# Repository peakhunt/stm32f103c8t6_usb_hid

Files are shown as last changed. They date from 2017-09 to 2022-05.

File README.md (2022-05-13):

# stm32f103c8t6_usb_hid

This is a USB joystick demo using STM32F103C8T6.
The whole project was developed using CubeMX.

## hardware
Basically I used very cheap chinese STM32F103 module. [The link is here][1]

As for arcade style joysticks and push buttons, there are a bunch of
cheap chinese stuffs out there.

As for connection, please refer to the kicad directory. It's gonna cost about $10 US dollars to get the 10 custom PCBs from cheap PCB manufactureres. Whether you use custom soldering or PCB based approach, just be sure to pay attention to the capacitor to prevent debouncing .  And just bear in mind that I am a S/W enginner. Designing a simple H/W like this is just a kind of my hobby.

[1]: https://www.aliexpress.com/item/Free-Shipping-STM32F103C8T6-ARM-STM32-Minimum-System-Development-Board-Module-For-arduino/32555258029.html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,searchweb201602_5_5460015_10152_10065_10151_10068_5470015_10307_10137_10060_10155_10154_10056_10055_10054_10059_100031_10099_10338_10339_5380015_10103_10102_440_10052_10053_10142_10107_10050_10051_10326_10084_10083_10080_10082_10081_10110_10175_10111_10112_10113_10114_143_10037_10312_10313_10314_10078_10079_10077_10073,searchweb201603_19,ppcSwitch_5&btsid=67a13b36-0190-4c70-9deb-1a2744050228&algo_expid=c62760bd-a140-4c3e-86ec-c725bdf3f0dc-14&algo_pvid=c62760bd-a140-4c3e-86ec-c725bdf3f0dc

## my build
Here is a demo joystick I built. I've been having some fun using it with retroarch. I love kungfu master.

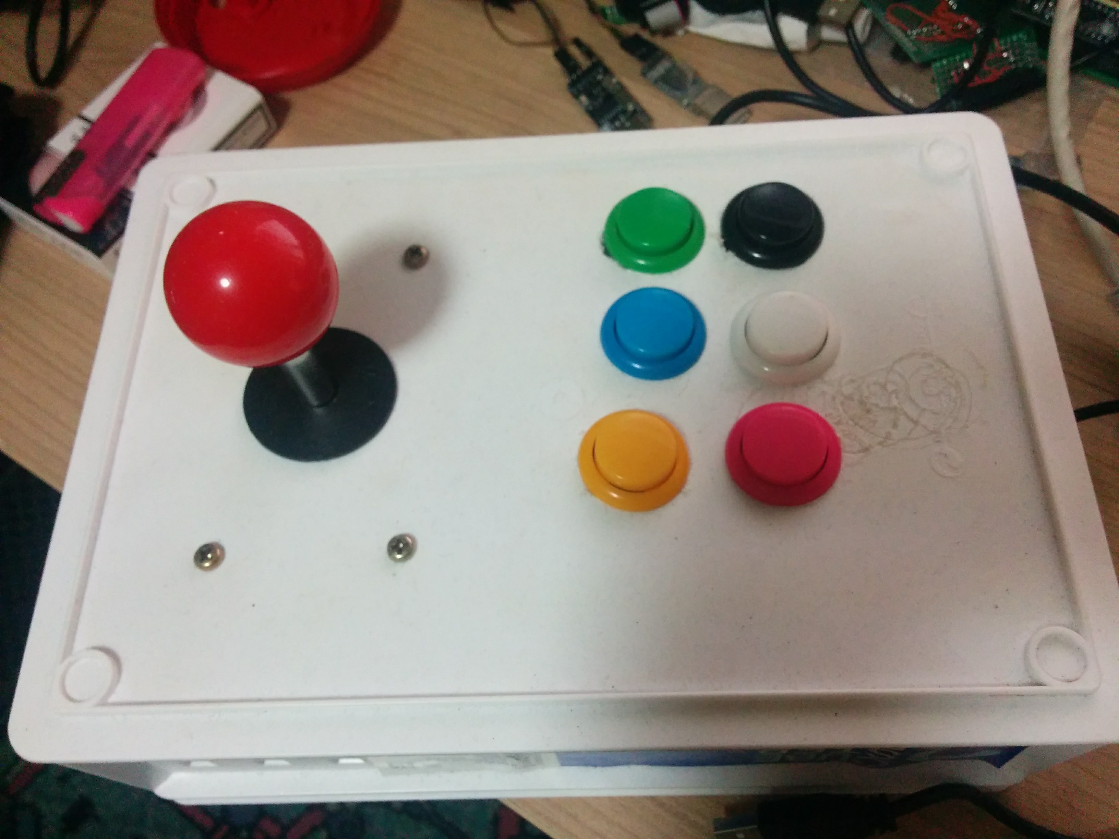
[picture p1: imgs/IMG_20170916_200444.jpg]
joystick build


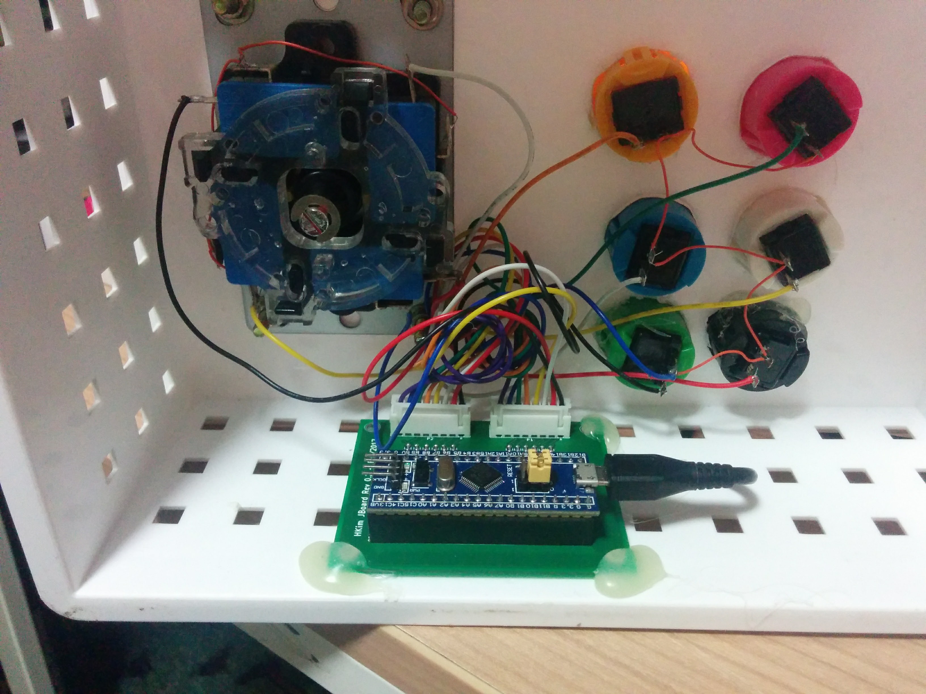
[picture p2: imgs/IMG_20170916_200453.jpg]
joystick build inside


The case is actually a small rectangular plastic container ( or basket or whatever). I bought it at less than 2 dollars at a local store and drilled it.

Here is the image of PCB I created for the build. It's really primitive simple board and anybody can do it. I just hated all the stupid fragile wiring I had to do before the PCB.

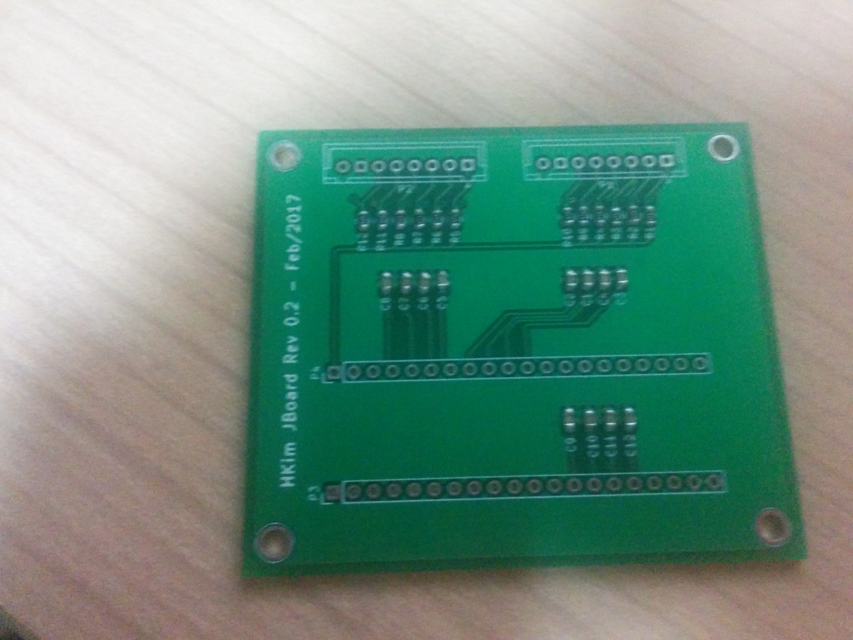
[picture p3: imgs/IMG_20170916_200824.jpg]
jostick board


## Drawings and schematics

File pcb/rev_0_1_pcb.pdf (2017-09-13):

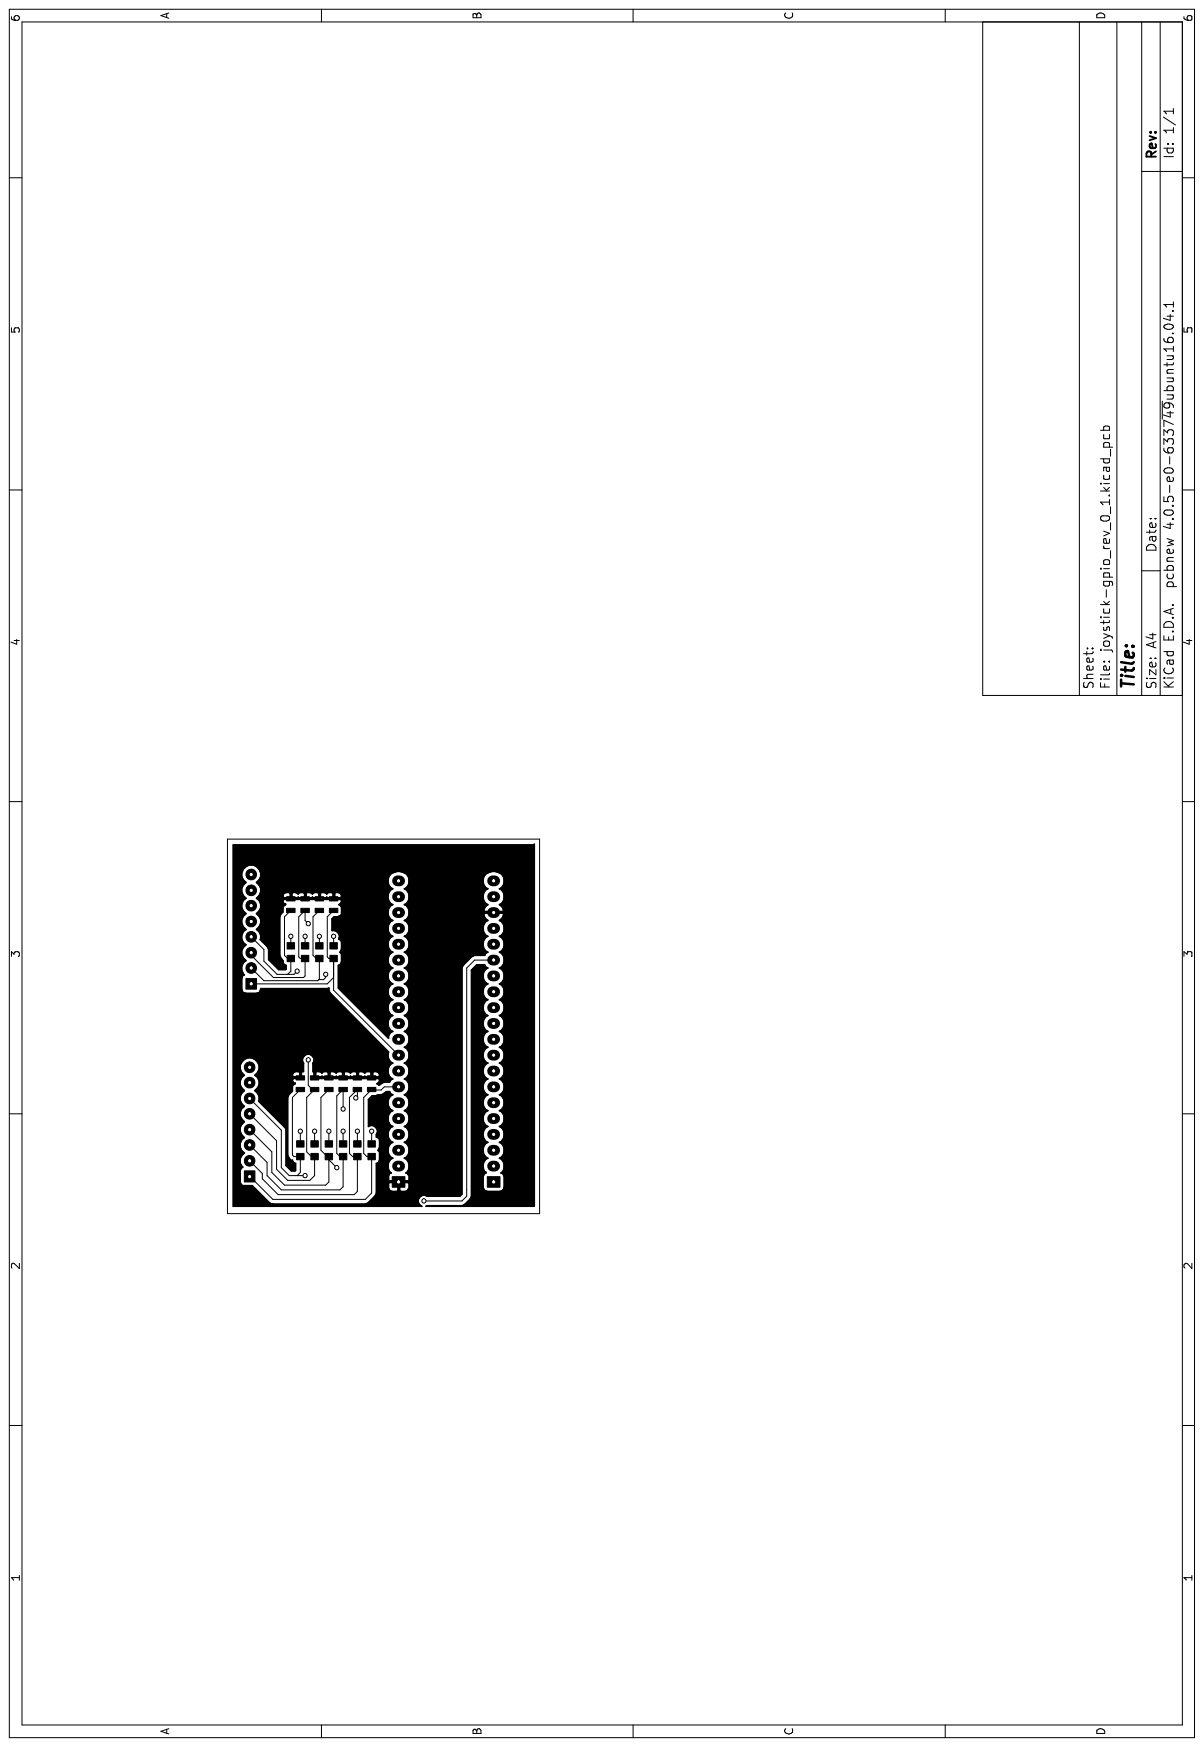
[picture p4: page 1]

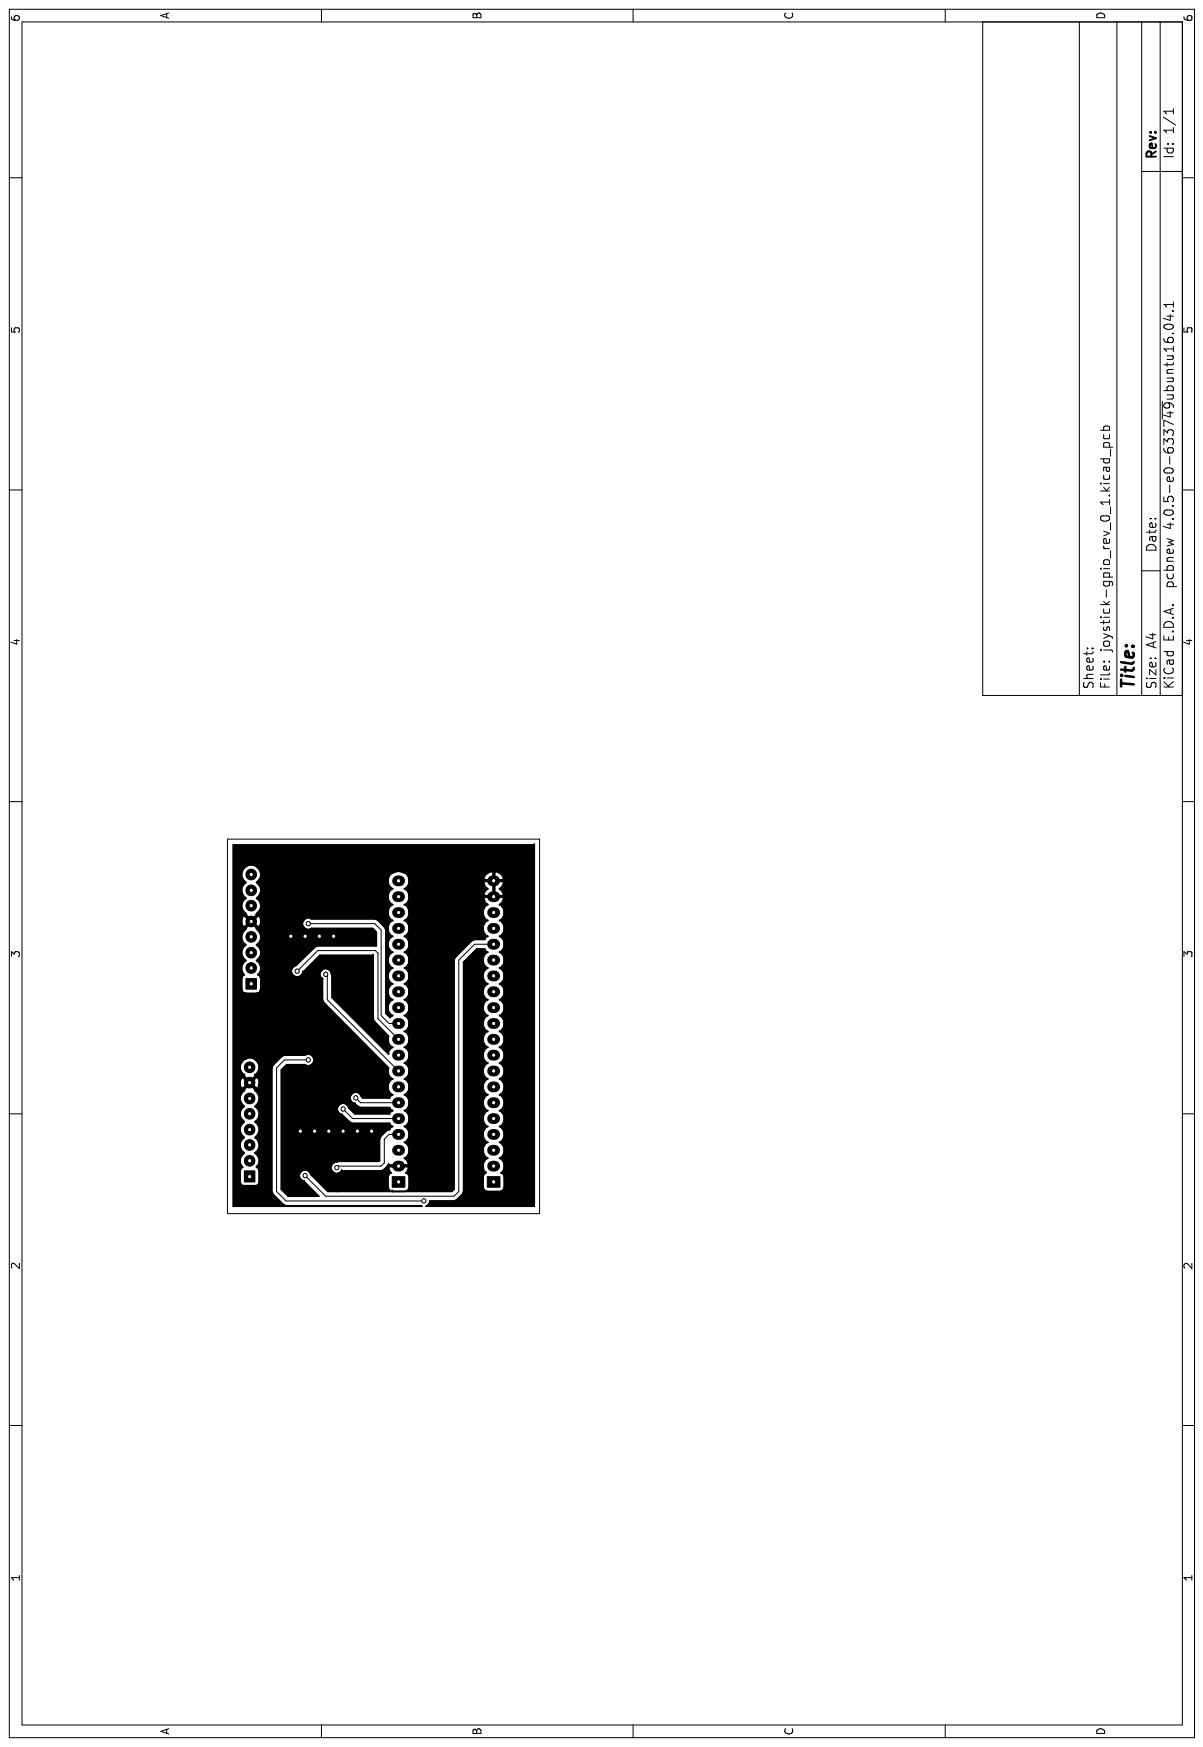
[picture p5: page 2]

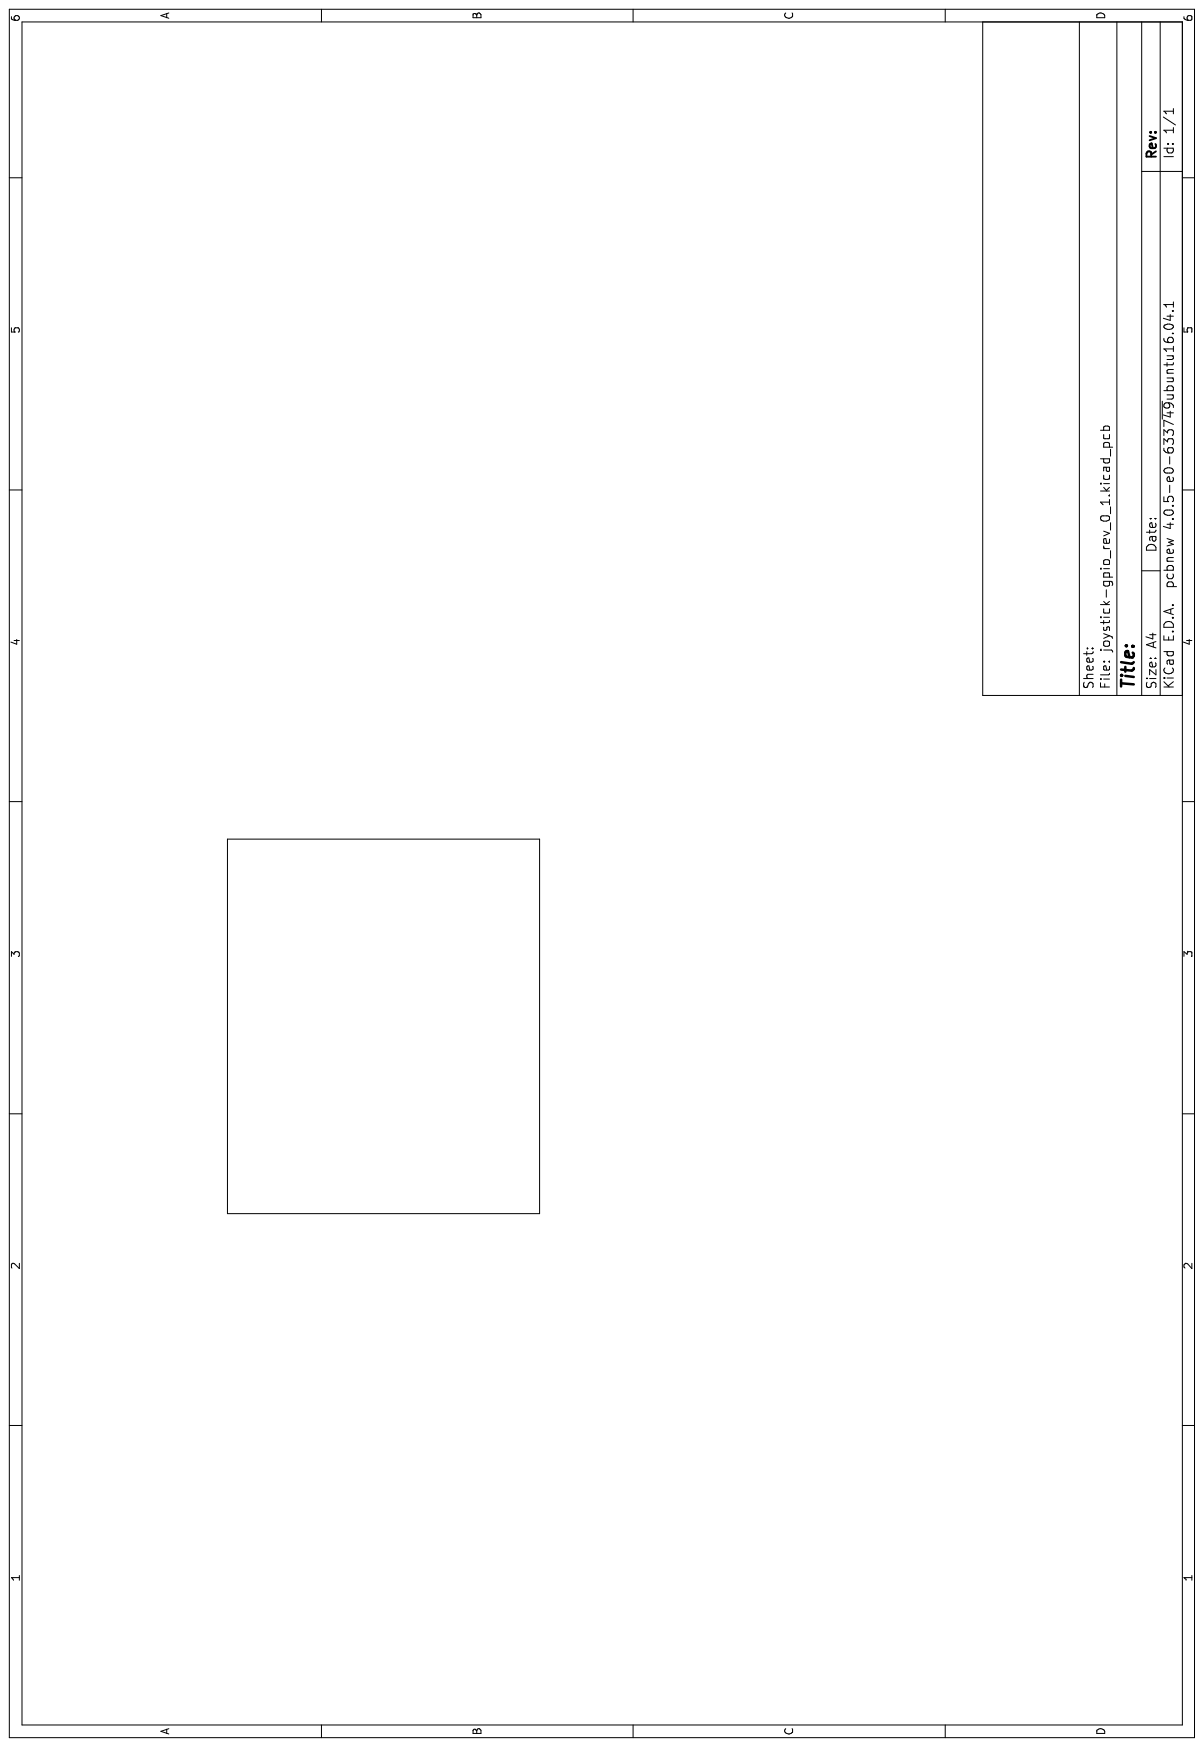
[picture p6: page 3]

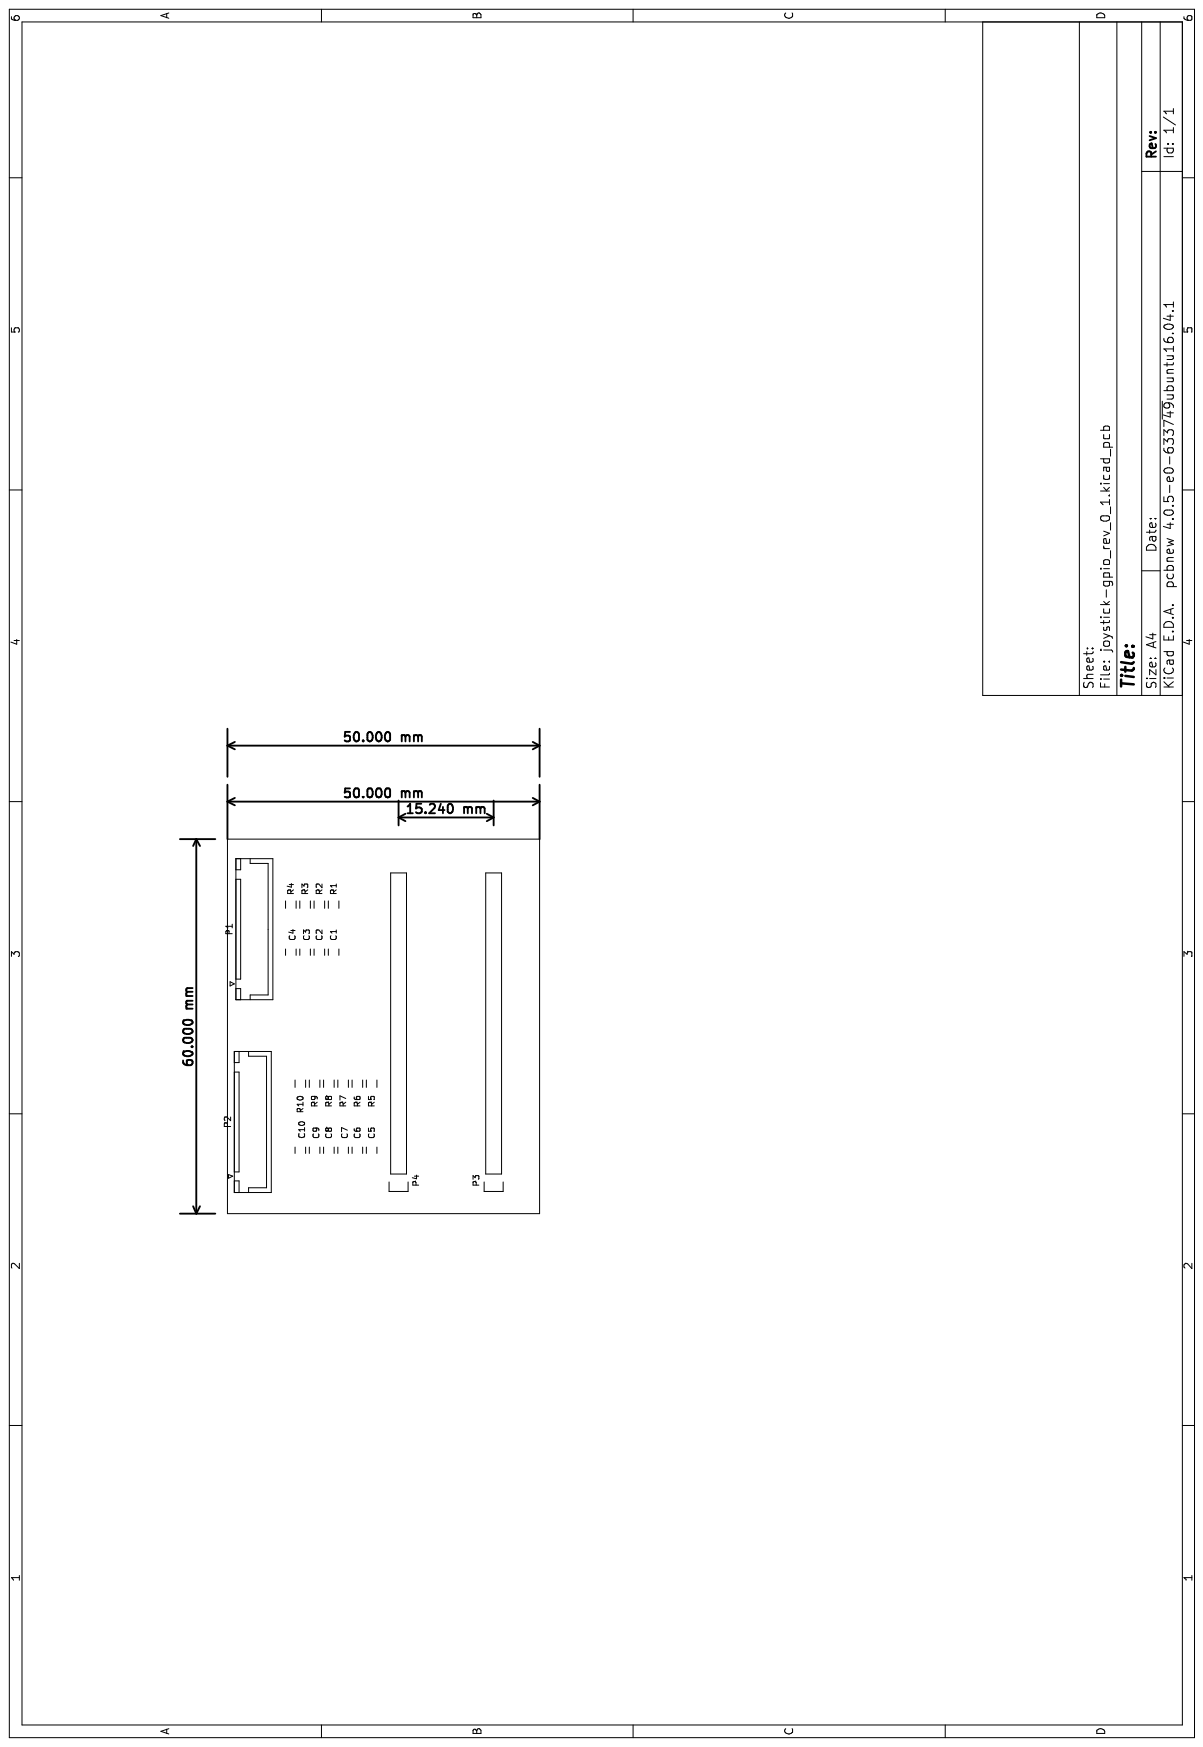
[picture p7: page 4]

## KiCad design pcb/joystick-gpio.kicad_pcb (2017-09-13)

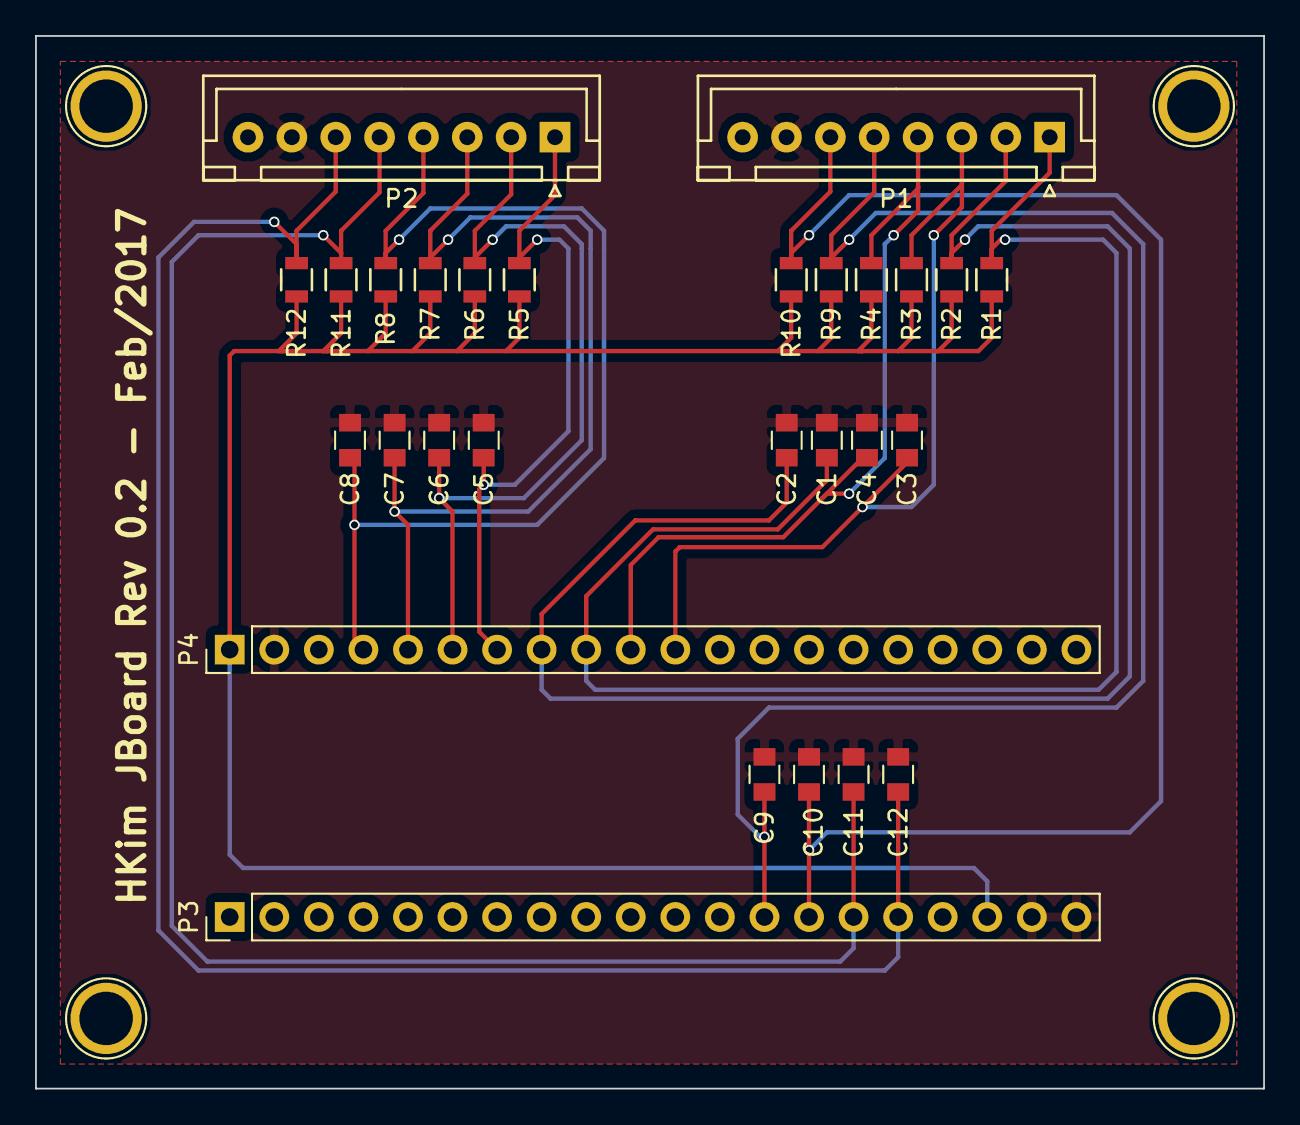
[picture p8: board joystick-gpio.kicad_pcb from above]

Board: 2 copper layers, 70.0 x 60.0 mm, 28 parts (0 on the bottom side), 14 nets.

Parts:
C1, C2, C3, C4, C5, C6, C7, C8, C9, C10, C11, C12: 100nF; C_0805
P1, P2: CONN_01X08; JST_XH_B08B-XH-A_08x2.50mm_Straight
P3, P4: CONN_01X20; Socket_Strip_Straight_1x20_Pitch2.54mm
R1, R2, R3, R4, R5, R6, R7, R8, R9, R10, R11, R12: 47K; R_0805

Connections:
/3.3V: P3.18, P4.1, R1.2, R2.2, R3.2, R4.2, R5.2, R6.2, R7.2, R8.2, R9.2, R10.2, R11.2, R12.2
/GROUND: C1.1, C2.1, C3.1, C4.1, C5.1, C6.1, C7.1, C8.1, C9.1, C10.1, C11.1, C12.1, P1.7, P2.7, P3.19, P3.20, P4.2
/JBT0: C5.2, P2.1, P4.7, R5.1
/JBT1: C6.2, P2.2, P4.6, R6.1
/JBT2: C7.2, P2.3, P4.5, R7.1
/JBT3: C8.2, P2.4, P4.4, R8.1
/JBT4: C9.2, P1.5, P3.13, R9.1
/JBT5: C10.2, P1.6, P3.14, R10.1
/JDOWN: C2.2, P1.2, P4.8, R2.1
/JLEFT: C3.2, P1.3, P4.11, R3.1
/JRIGHT: C4.2, P1.4, P4.10, R4.1
/JSELECT: C12.2, P2.6, P3.16, R12.1
/JSTART: C11.2, P2.5, P3.15, R11.1
/JUP: C1.2, P1.1, P4.9, R1.1

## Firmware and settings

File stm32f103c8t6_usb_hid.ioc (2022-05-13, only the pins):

Mcu.UserName=STM32F103C8Tx
PA0-WKUP.Signal=ADCx_IN0
PA1.Signal=ADCx_IN1
PA11.Signal=USB_DM
PA12.Signal=USB_DP
PA13.Signal=SYS_JTMS-SWDIO
PA14.Signal=SYS_JTCK-SWCLK
PA15.GPIO_Label=joystick_left
PA15.Signal=GPIO_Input
PA2.Signal=ADCx_IN2
PA3.Signal=ADCx_IN3
PA4.Signal=ADCx_IN4
PA5.Signal=ADCx_IN5
PA6.Signal=ADCx_IN6
PA7.Signal=ADCx_IN7
PB10.Signal=I2C2_SCL
PB11.Signal=I2C2_SDA
PB12.Signal=SPI2_NSS
PB13.Signal=SPI2_SCK
PB14.Signal=SPI2_MISO
PB15.Signal=SPI2_MOSI
PB3.GPIO_Label=joystick_right
PB3.Signal=GPIO_Input
PB4.GPIO_Label=joystick_up
PB4.Signal=GPIO_Input
PB5.GPIO_Label=joystick_down
PB5.Signal=GPIO_Input
PB6.GPIO_Label=joystick_button0
PB6.Signal=GPIO_Input
PB7.GPIO_Label=joystick_button1
PB7.Signal=GPIO_Input
PB8.GPIO_Label=joystick_button2
PB8.Signal=GPIO_Input
PB9.GPIO_Label=joystick_button3
PB9.Signal=GPIO_Input
PC13-TAMPER-RTC.GPIO_Label=led
PC13-TAMPER-RTC.Signal=GPIO_Output
PD0-OSC_IN.Signal=RCC_OSC_IN
PD1-OSC_OUT.Signal=RCC_OSC_OUT

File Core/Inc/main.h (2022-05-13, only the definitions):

#define led_Pin GPIO_PIN_13
#define led_GPIO_Port GPIOC
#define joystick_left_Pin GPIO_PIN_15
#define joystick_left_GPIO_Port GPIOA
#define joystick_right_Pin GPIO_PIN_3
#define joystick_right_GPIO_Port GPIOB
#define joystick_up_Pin GPIO_PIN_4
#define joystick_up_GPIO_Port GPIOB
#define joystick_down_Pin GPIO_PIN_5
#define joystick_down_GPIO_Port GPIOB
#define joystick_button0_Pin GPIO_PIN_6
#define joystick_button0_GPIO_Port GPIOB
#define joystick_button1_Pin GPIO_PIN_7
#define joystick_button1_GPIO_Port GPIOB
#define joystick_button2_Pin GPIO_PIN_8
#define joystick_button2_GPIO_Port GPIOB
#define joystick_button3_Pin GPIO_PIN_9
#define joystick_button3_GPIO_Port GPIOB

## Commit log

2017-09-13 adding kicad schematics
    [joystick-gpio-B.Cu.gbr, joystick-gpio-B.Mask.gbr, joystick-gpio-B.SilkS.gbr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]
2017-09-16 adding sample pictures
2022-05-13 it's been a while. a new mechanism
    [joystick-gpio-B.Cu.gbr, joystick-gpio-B.Mask.gbr, joystick-gpio-B.SilkS.gbr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]
2022-05-13 readding simple old primitive pcb
    [joystick-gpio-2022-04-14-17-56-57.sch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]
2022-05-20 changed HID IN interrupt EP's max packet size to 4. still investigating why 64 isn't working
2022-05-20 solving max 64 bytes packet length problem
    [hid.c]

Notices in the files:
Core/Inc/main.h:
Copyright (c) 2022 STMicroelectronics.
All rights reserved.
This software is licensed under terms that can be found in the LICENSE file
